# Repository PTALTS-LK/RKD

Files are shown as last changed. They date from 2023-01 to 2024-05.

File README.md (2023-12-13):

# RP2040-based Keyboard Devkit

**这是一个基于RP2040以及CH9329键鼠芯片的，使用Kicad6.0设计的一个开源音游控制器**

你也能当成一个可编程键盘使用

**使用MicroPython作为程序主控**
<!-- 只是一个高一学生用业余时间整出来的垃圾项目罢了，PCB布线设计以及代码什么的肯定有很多问题（ -->

<details><summary>

### 预览

</summary>

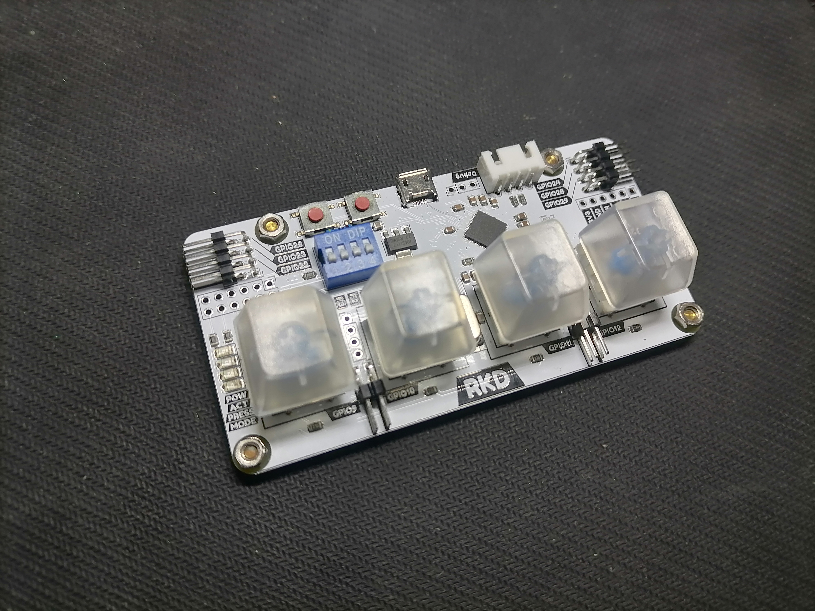
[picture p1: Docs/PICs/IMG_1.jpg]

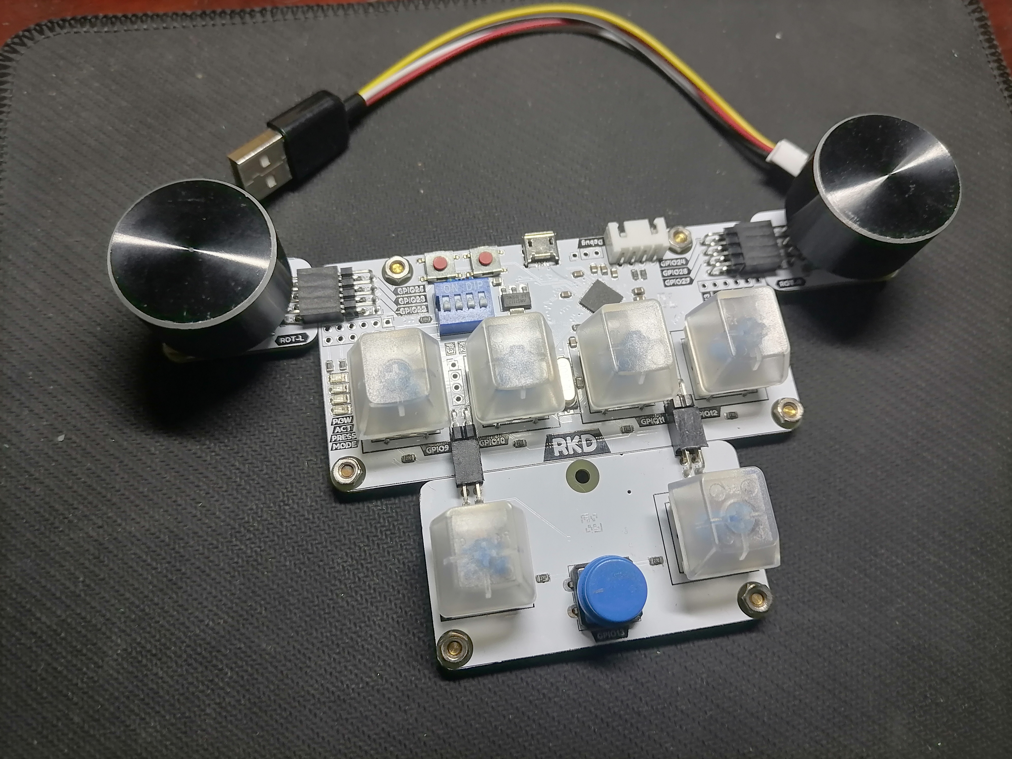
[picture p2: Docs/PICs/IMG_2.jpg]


</details>

## 特征：

  - （主要是）一个可编程键盘/4k音游控制器
    - PCB预设了SDVX的拓展板，也有只有主板的PCB
  - 使用CH9329键鼠芯片，可以模拟鼠标~~我没做~~或者键盘
  - 将RP2040的所有空闲GPIO和板载四个键使用排针引出
    - 可以用杜邦线外接按键/其他外设
    - 保留了SWD，你甚至当成一般的arm开发板进行开发
  - 键位可以~~不怎么~~方便的设置
    - 板上Flash fat32文件系统config.json，USB大容量设备写入有概率文件损坏，建议Thonny写入
    - 基于串口命令的设置系统,详见文档
  - 支持四种按键预设切换,通过板载DIP开关
  - 内置了宏执行器（格式请参照~~目前并不存在的~~文档）
  - 使用机械键盘键轴，可插拔（使用MX轴体）
  - 接口有MicroUSB和Type-C两种版本
  - ~~***没了***~~

## 项目文件结构
  [Docs](Docs) 各种文档

  [PCB](PCB) 当前版本的电路板Kicad设计文件

  [MPY_code](MPY_code) Micropython主控程序

  Micropython固件可在 [RKD-MpyPort](https://github.com/PTALTS-LK/RKD-MpyPort) 的Release页面找到

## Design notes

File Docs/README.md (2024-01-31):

# RKD文档

[Visual-BOM_gerber](Visual-BOM_gerber) 项目元件摆放位号的可视化BOM和gerber文件

[BOM.md](BOM.md) 项目的物料清单

[thonny_dev.md](thonny_dev.md) 更改键位和进行开发的说明（使用Thonny,不推荐用于修改键位）

[key_map.md](key_map.md) 按键对应键值的说明

[MAKE.md](MAKE.md) 制作注意事项

[Wire-key-positioning.md](Wire-key-positioning.md) 关于如何焊接钢丝键轴固定

[cdc_setting.md](cdc_setting.md) 通过串口来设置键位的说明

[RKD.dxf](RKD.dxf) 外壳切割文件

## 引脚图

RKD-Pinout

## 建议

**欢迎对文档提出建议或纠错**

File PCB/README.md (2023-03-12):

# PCB/原理图

- stand+sdvx :

  - 包含了主板和SDVX拓展板的PCB/原理图（单文件拼板）

- stand :

  - 只包含了主板PCB/原理图

子目录名称为对应接口版本的PCB/原理图

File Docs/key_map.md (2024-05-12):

# 按键键值对照

还可以参考MPY_code中[tools.py](https://github.com/PCX-LK/RKD-MpyCode/blob/979dd39ad3c4af1102518f772fbc5197f3a658ba/code/lib/tools.py)中的key_dict函数来设置键位

在串口中修改键位时,请不要带双引号

## 特殊键码

`NULL`  “空”按键，将按键设置为这个键码可以让按键空闲

## 数字键区

|按键名|对应键值|
| :---: | :---: |
|1 !|"1"|
|2 @|"2"|
|3 #|"3"|
|4 $|"4"|
|5 %|"5"|
|6 ^|"6"|
|7 &|"7"|
|8 *|"8"|
|9 (|"9"|
|0 )|"0"|

## 字母键区

|按键名|对应键值|
| :---: | :---: |
|Q|"Q"|
|W|"W"|
|E|"E"|
|R|"R"|
|T|"T"|
|Y|"Y"|
|U|"U"|
|I|"I"|
|O|"O"|
|P|"P"|
|A|"A"|
|S|"S"|
|D|"D"|
|F|"F"|
|G|"G"|
|H|"H"|
|J|"J"|
|K|"K"|
|L|"L"|
|Z|"Z"|
|X|"X"|
|C|"C"|
|V|"V"|
|B|"B"|
|N|"N"|
|M|'M'|

## 符号键区

|按键名|对应键值|
| :---: | :---: |
|\` ~|"`"|
|- _|"-"|
|= +|'='|
|\\ \||\\|
|; :|";"|
|' "|"'"|
|, <|"<"|
|. >|"."|
|/ ?|"/"|
|Space|" "|

## 功能键区

|按键名|对应键值|
| :---: | :---: |
|ESC|"ESC"|
|Enter|"Enter"|
|BackSpace|"BackSpace"|
|Tab|"Tab"|
|CapsLock|"CapsLock"|
|Left Shift|"ShiftL"|
|Right Shift|"ShiftR"|
|Left Ctrl|"CtrlL"|
|Right Ctrl|"CtrlR"|
|Left Alt|"AltL"
|Right Alt|"AltR"
|Left Win|"WinL"|
|Right Win|"WinR"|
|Insert|"Insert"|
|Delete|"Delete"|
|Home|"Home"|
|End|"End"|
|PrintScreen|"PrintScreen"|
|ScrollLock|"ScrollLock"|
|Pause|"Pause"|
|PageUp|"PageUp"|
|PageDown|"PageDown"|
|Application|"App"|
|UpArrow|"UpArrow"|
|DownArrow|"DownArrow"|
|LeftArrow|"LeftArrow"|
|RightArrow|"RightArrow"|

## Function键区

|按键名|对应键值|
| :---: | :---: |
|F1|"F1"|
|F2|"F2"|
|F3|"F3"|
|F4|"F4"|
|F5|"F5"|
|F6|"F6"|
|F7|"F7"|
|F8|"F8"|
|F9|"F9"|
|F10|"F10"|
|F11|"F11"|
|F12|"F12"|

# 小键盘区

|按键名|对应键值|
| :---: | :---: |
|NumLock|"NumLock"|
|/|"n/"|
|\*|"n\*"|
|-|"n-"|
|+|"n+"|
|.|"n."
|Enter|"nEnter"|
|1|"n1"|
|2|"n2"|
|3|"n3"|
|4|"n4"|
|5|"n5"|
|6|"n6"|
|7|"n7"|
|8|"n8"|
|9|"n9"|
|0|"n0"|

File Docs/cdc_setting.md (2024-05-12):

# 使用串口进行键位修改

最近的主控更新中更新了基于串口的指令设置方式（目前只支持更改按键）

支持PC（Windows,Linux,OSX）端以及Android端

## 安装串口通信软件

如果你有其他的串口软件并且会使用,可以不用完全按照下文来做

### PC端

请根据自己的平台前往COMTool的[Sourceforge](https://sourceforge.net/projects/comtool/files)下载安装文件

- Windows用户请下载`comtool_windows_<COMTool版本>.7z`
- Linux用户请下载`comtool_ubuntu_<COMTool版本>.tar.xz`结
- OSX用户请下载`comtool_macos_<COMTool版本>.dmg`

### Android端

请前往F-droid或者Google Play下载`Serial USB Terminal`

你还需要一根OTG线

## 使用串口通信软件连接RKD

连接之前确保RKD的`F3`没有上拨,如果上拨了,请拨下之后按下`RUN`按钮

### PC端 (COMTool)

使用调试线连接PC与RKD

连接之后打开`COMTool`

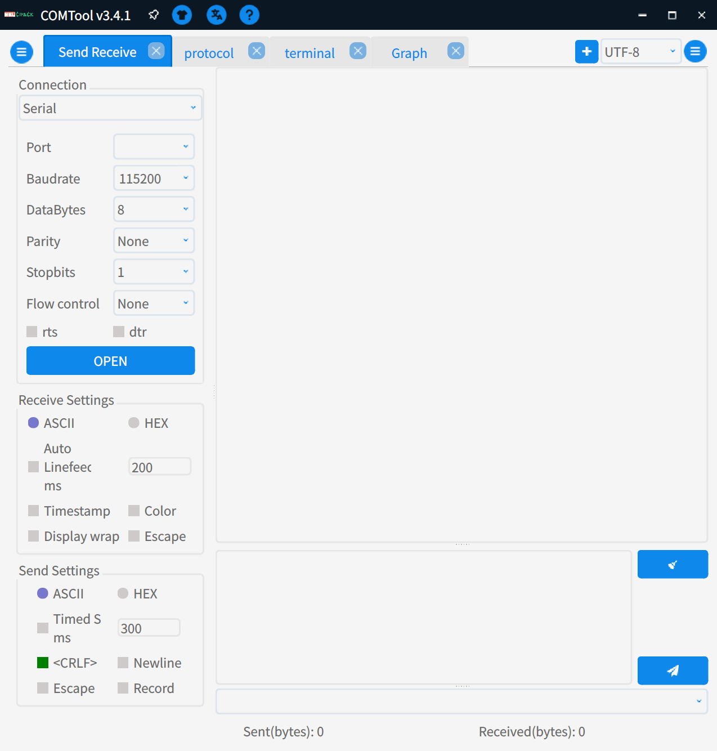
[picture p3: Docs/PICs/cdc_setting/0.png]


点击这个图标来设置语言，然后点击`Yes`来确认重启



`连接`面板配置:
- 打开`dtr`
- 点击`端口`下拉框来选择端口,应选择带有`RKD`字样的端口(Windows用户需要寻找`Microsoft - pid(0x04A0)`)
- 其余保持默认

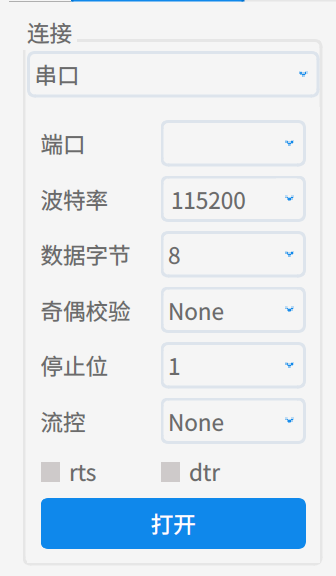
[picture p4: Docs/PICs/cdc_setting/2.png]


`发送设置`面板配置:
- 勾选`新行`
- 其余保持默认

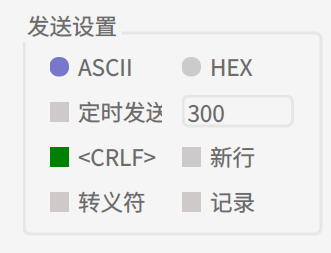
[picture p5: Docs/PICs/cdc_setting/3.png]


点击`连接`面板中的`打开`来连接到端口



之后上拨RKD的`F3`,此时接收面板应输出以下内容则证明连接成功

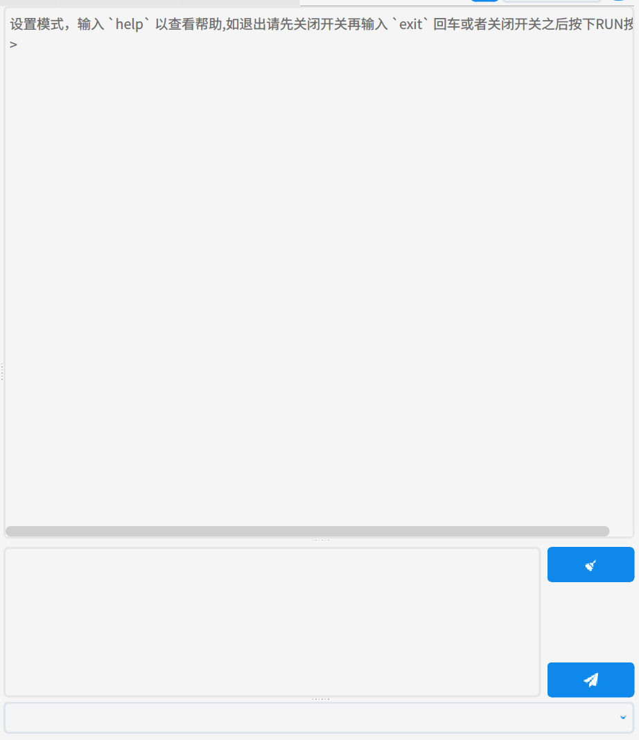
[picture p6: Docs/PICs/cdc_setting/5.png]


在发送面板输入`help`,然后按下右边的纸飞机(发送)按钮,接收面板内容应如下

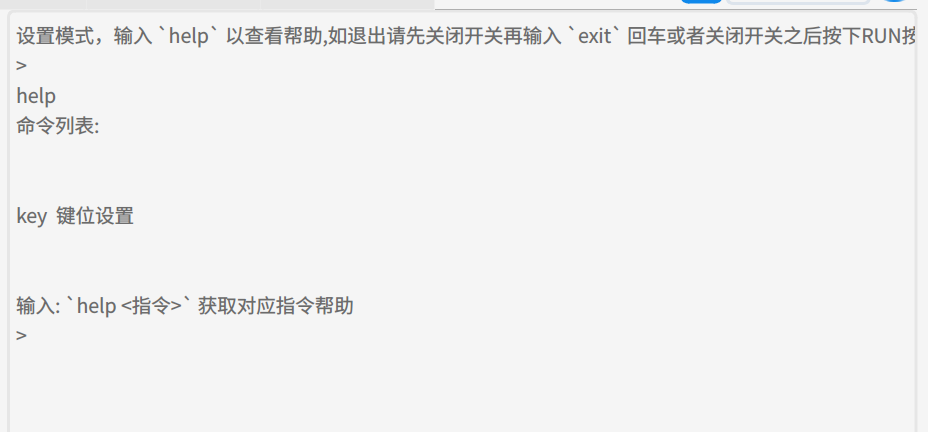
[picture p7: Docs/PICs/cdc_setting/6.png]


### 使用Thonny的shell来修改 (PC端)

先按照[thonnt_dev.md](thonny_dev.md)中的方法来配置thonny

然后使用调试线连接PC与RKD

打开`Thonny`,然后拨上RKD的`F3`,此时应该出现

th-o

进入设置模式成功

### Android端 (Serial USB Terminal)

使用OTG线+调试线连接RKD与Android设备

- 如果连接没有反应（RKD的电源指示灯`POW`未亮起）

  则有可能你的手机需要在设置中手动开启OTG功能，如何开启请根据自己的手机品牌型号自行百度

连接之后打开`Serial USB Terminal`

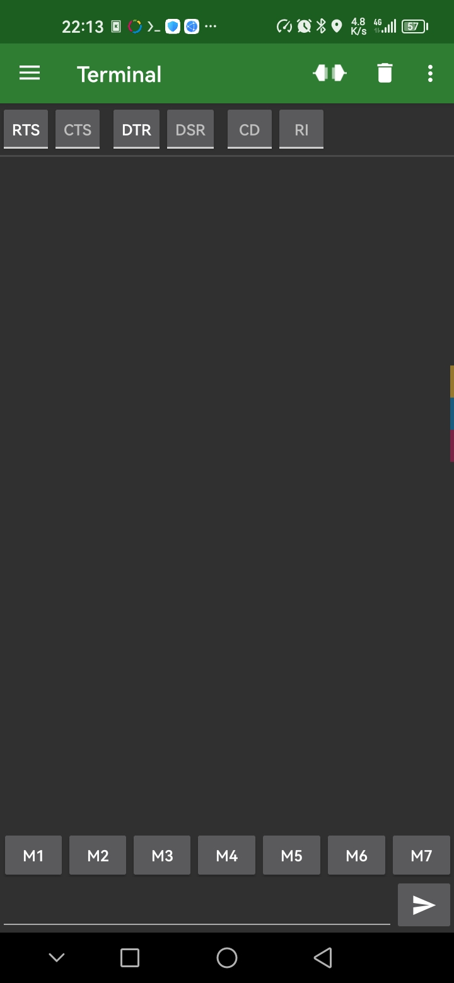
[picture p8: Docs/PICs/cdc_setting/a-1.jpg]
a-1


点击右上角的连接图标

a-2

此时应该会弹出一个授权窗口,点确定

然后上拨RKD的`F3`

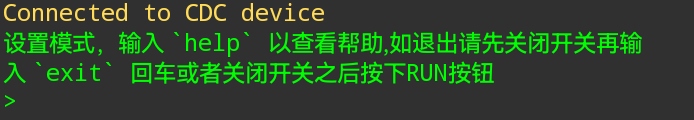
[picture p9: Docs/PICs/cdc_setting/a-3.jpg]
a-3


如果出现以上内容则证明连接成功

## 进行键位修改

可以先输入`help`来查看可用的命令

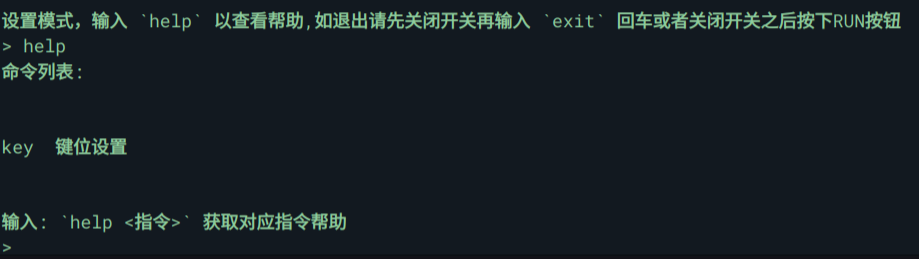
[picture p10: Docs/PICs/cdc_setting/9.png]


目前只有`key`,用于获取键位设置和修改键位

可以输入`help <指令>` (不需要添加尖括号) 来查看对应指令的参数帮助

### 命令

可以通过`key getKeyList`来获取所有按键所对应的键名,`key getKeyMap`来获取键值

然后通过`key setKeyValue`来设置键的映射:
- 语法：`key setKeyValue <键名> <键值1> <键值2> ....`
  一次只能设置一个键名对应的键值,可以有多个键值(可以实现组合键,同时按下的最多有效数量只有6个)
  修改的时候,注意RKD上`F1` `F2`的状态,这个两个开关决定了修改哪个预设组,用二进制的方式来设置预设组,上拨为1,下拨为0

  比如:
  ```
  F2  F1
  上  下
  ```
  对应二进制`10`,十进制`2`
  也就是3号预设
  ```
  F2  F1
  下  下
  ```
  对应二进制`00`,十进制`0`
  也就是1号预设
  
  对命令`key getKeyGroupValue`以及`key getKeyValue`同样生效

  在非设置模式下也是通过这个方式来切换预设组

  当boot_mode为0时才有效,为1时不支持多预设切换(只有一号预设组),目前boot_mode写死在了主控代码中(普通用户不用理会,默认为0)

`key getKeyGroupValue`和`key getKeyValue`:
- 用于获取整个当前预设组或者当前预设组特定键名对应按键键值
  `getKeyValue`需要指定键名,而`getKeyGroupValue`不需要(因为直接获取当前整个组)

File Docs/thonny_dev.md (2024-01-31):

# 使用Thonny IDE进行键位设置/开发

## 已不再推荐使用该方法修改键位

## 1 - 安装Thonny

### 1.1 - Windows

如果你是Windows用户，请前往Thonny的[官网](https://thonny.org/)或者Github的[Release页面](https://github.com/thonny/thonny/releases)下载exe安装程序

#### 1.1.1 - 在官网或在Github Release下载安装程序

**在Thonny官网或者Github Release页面下载安装程序**

##### **Thonny[官网](https://thonny.org/)**

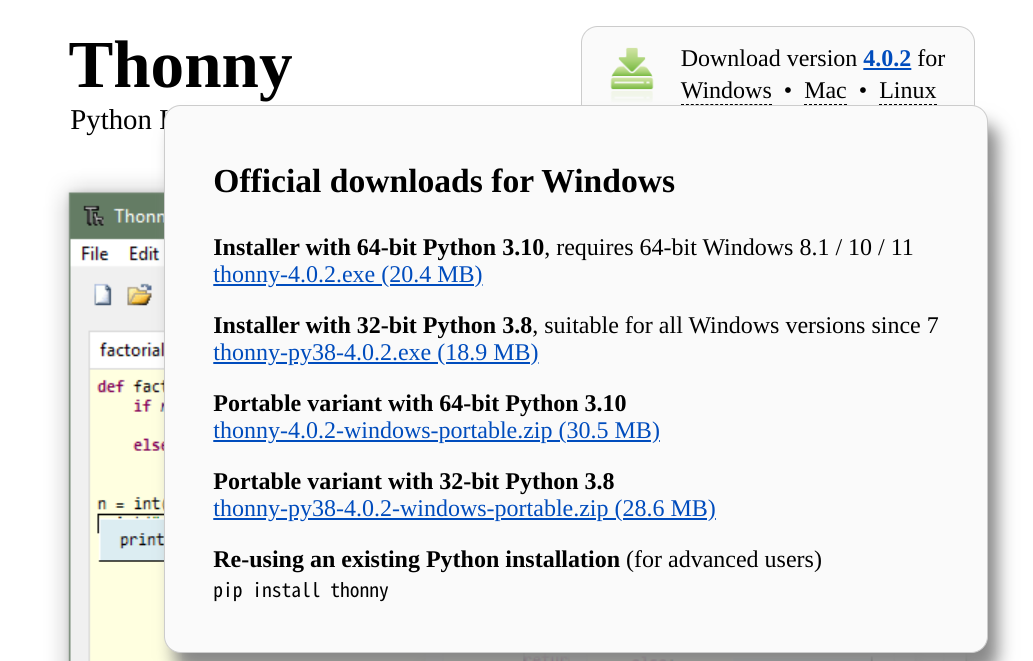
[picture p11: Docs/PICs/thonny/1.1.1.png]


鼠标悬浮在"Windows"上，会弹出菜单

如果你的系统是Win7或者是32位，则应该选择
```
Installer with 32-bit Python 3.8
thonny-py38-x.x.x.exe
```

如果是Win7以上而且是64位的系统，则应该选择
```
Installer with 64-bit Python 3.10
thonny-x.x.x.exe
```

##### **Github [Release页面](https://github.com/thonny/thonny/releases)**

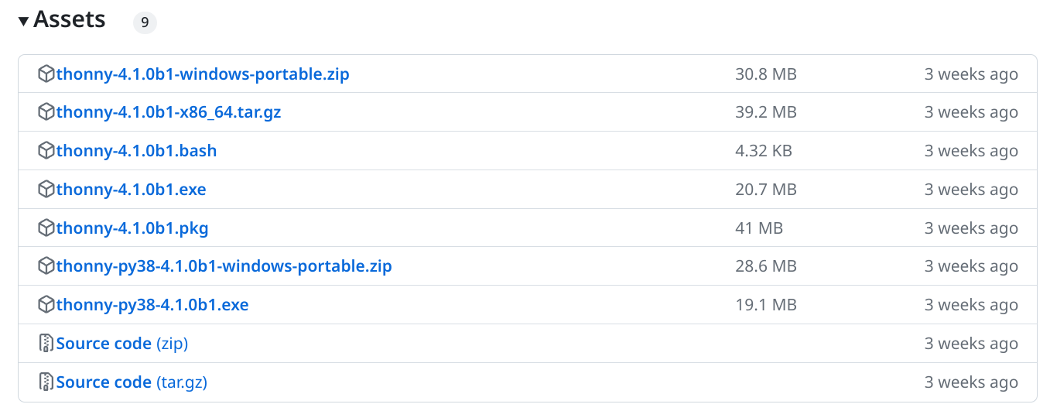
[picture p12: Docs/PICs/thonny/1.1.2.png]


在展开Assets之后

如果你的系统是Win7或者是32位，则应该选择
```
thonny-py38-x.x.x.exe
```

如果是Win7以上而且是64位的系统，则应该选择
```
thonny-x.x.x.exe
```

#### 1.1.3 - 运行安装程序

下载完毕后运行下载的exe进行安装，进入下一步

安装完后请从桌面的Thonny快捷方式或者开始菜单启动Thonny，而不是再次启动安装exe！

### 1.2 - Linux

如果你是Debian系用户，执行以下命令即可安装（其他发行版用户请自行摸索安装方法）

```
sudo apt install thonny -y
```

如果软件源的Thonny比较老，则再执行以下指令更新（推荐pip换源后执行）
```
pip install --upgrade thonny --break-system-packages
```

### 1.3 - OSX

高贵的Mac用户请自行摸索安装方法（（

## 2 - 设置Thonny

### 2.1 - 初始设置

首次启动thonny会弹出这个窗口

在这里选择语言和初始配置

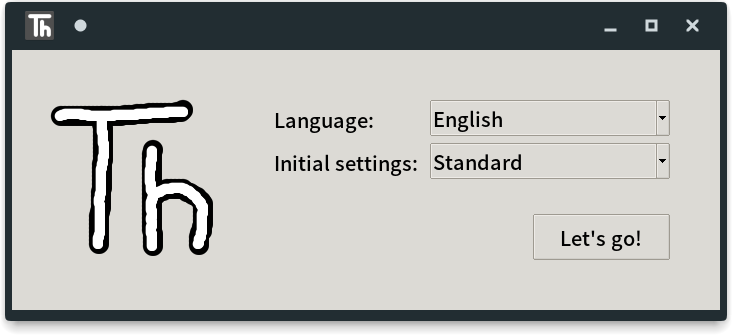
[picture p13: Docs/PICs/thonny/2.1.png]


"Language"不用说，直接选择"简体中文"

"Initial settings"是初始配置，这里原封不动选择"Standard"，不要选择"Raspberry pi"，界面布局会变成依托答辩

然后点击"Let's go!"进入下一步

### 2.2 - 界面布局设置

不出意外的话，你的界面应该是这个样子

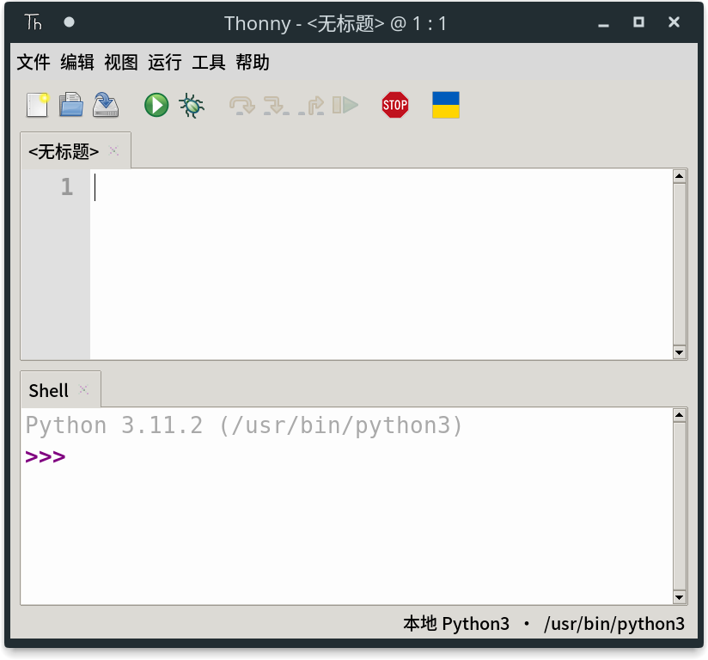
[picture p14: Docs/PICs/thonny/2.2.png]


点击工具栏中的"视图"，中勾选"文件"

这时视图应该会变成这样

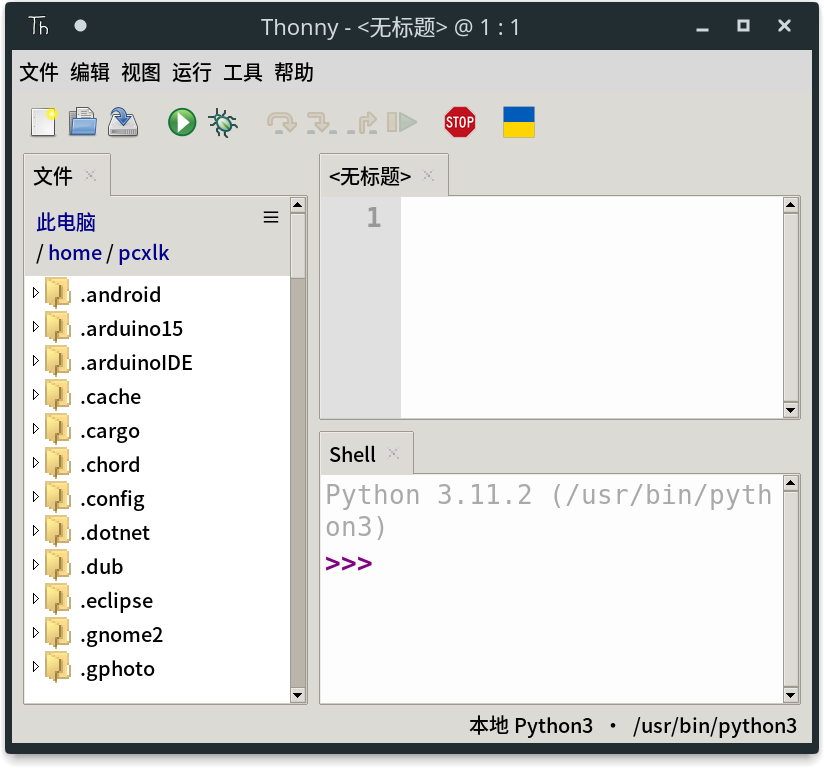
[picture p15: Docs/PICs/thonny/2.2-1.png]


### 2.3 - 设置解释器

现在thonny的默认解释器还是系统中/自带的Pyhon环境，我们需要将其切换到"Micropython"解释器

点击工具栏中的"运行"，在点击"选择解释器"，会弹出Thonny的设置窗口

将"Thonny 应该使用哪种解释器来运行您的代码？"下拉框的内容更改为"Micropython (通用)"或者"Micropython (RP2040)"

取消勾选"连接时中断运行中的程序"和"运行代码前，先重启解释器"复选框

设置完后界面应该是这样

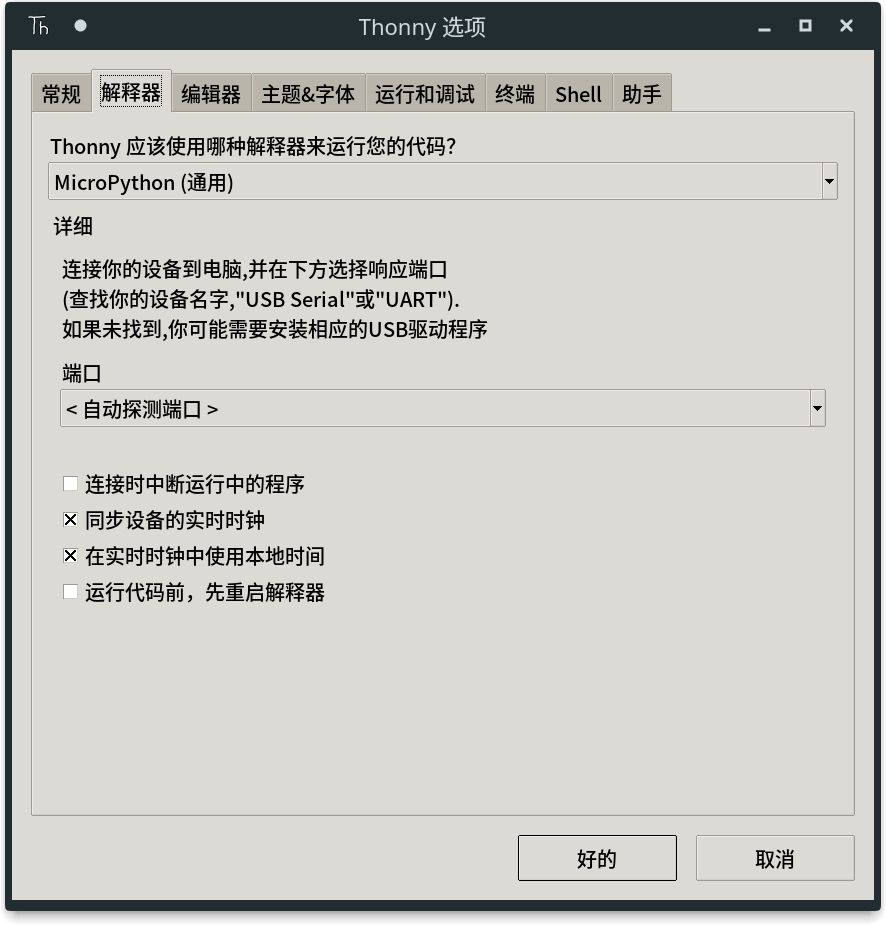
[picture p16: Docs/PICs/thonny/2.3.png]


点击"好的"保存退出设置

## 3 - 使用Thonny进行键位更改/开发
<!--  -->
### 3.1 - 连接RKD & 将Thonny连接到RKD上的MPY REPL

首先使用调试线连接RKD到电脑上，系统把设备设置完毕后会在资源管理器中多出一个3mib容量的usb存储设备，不要使用资源管理器打开它

回到Thonny，先按下界面左上方的红色"停止/重启后端进程"按钮或者按下Ctrl+F2

stop

如果界面底下shell面板输出如下（找无法自动找到设备）

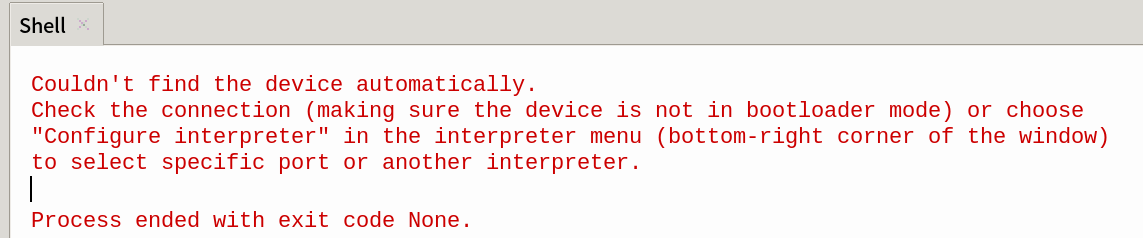
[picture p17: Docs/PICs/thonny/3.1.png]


请去设置解释器的页面中在端口下拉框中选择设备"Board in FS mode - Board CDC"



点击"好的"保存之后，shell面板应该输出如下，意思是设备忙于运行而无法响应

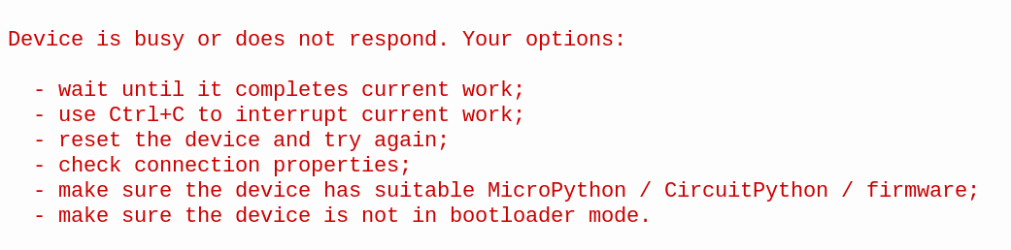
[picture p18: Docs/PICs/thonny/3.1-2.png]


所以要在shell面板里面按下Ctrl+C终止RKD板上主控的运行，此时应该输出为下

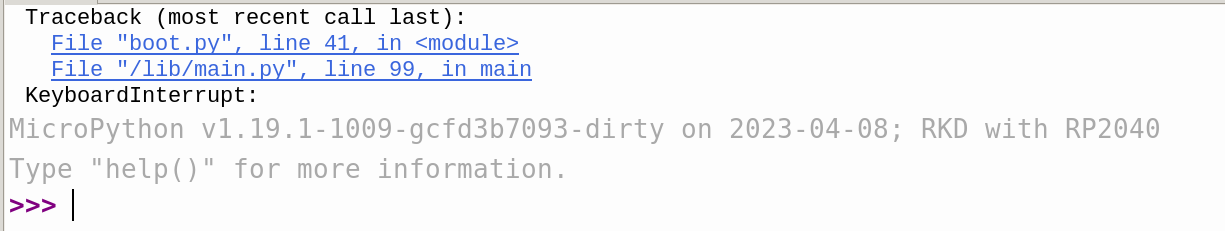
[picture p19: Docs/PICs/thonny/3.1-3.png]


然后你就会发现界面左边的"MicroPython设备"面板加载出了文件

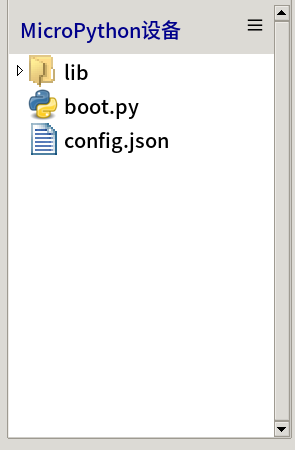
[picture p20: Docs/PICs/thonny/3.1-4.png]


这些文件储存在RKD主板上面的Flash中，"boot.py"文件和"lib"文件夹是RKD所运行的程序和依赖库

### 3.2 - 修改键位

只需要双击打开并修改"MicroPython设备"面板中的"config.json"就能修改键位

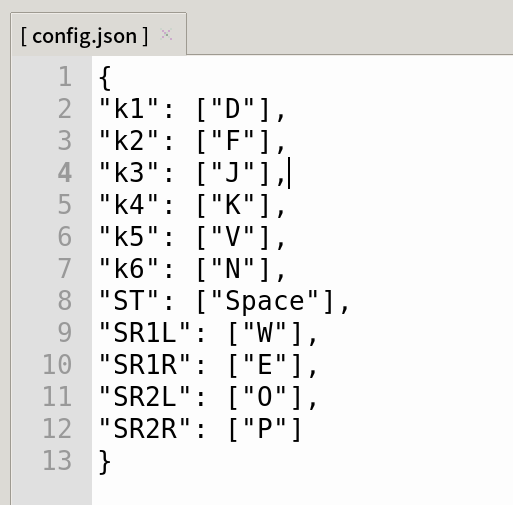
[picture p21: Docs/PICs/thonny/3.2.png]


冒号前面为按键，冒号后面为该键对应的键值

只需要修改键值就能更改键位

按键名对应：
```
主板部分：
k1 从左往右数第一个键
k2 从左往右数第二个键
k3 从左往右数第三个键
k4 从左往右数第四个键

SDVX扩展板部分：
k5 底板的从左往右第一个键
k6 底板的从左往右第二个键
ST 底板中间的按钮
SR1L 左旋钮逆时针旋转
SR1R 左旋钮顺时针选择
SR2L 右旋钮逆时针旋转
SR2R 右旋钮顺时针旋转
```

这些按键都可以设置组合键，只需要按照json的格式在按键后的数组中追加即可

键值对应请查看[key_map.md](key_map.md)

修改完成按Ctrl+S保存

然后在shell面板中按下Ctrl+D即可恢复运行，之后就可以关掉Thonny了

### 3.3 - 开发

可以参考网络上的使用Thonny IDE开发Micropython的教程

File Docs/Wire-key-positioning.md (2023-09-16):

# 钢丝键轴定位焊接说明

## 你需要什么

1. pcb中附带的钢丝辅助板
2. 0.5mm直径的304不锈钢钢丝
3. 能剪动2.中钢丝的尖嘴钳(可以单独使用强度够高的斜口钳,但是尖嘴钳还是需要的)
4. 电烙铁和焊锡
5. pcb(不可能没有吧)

## 步骤

### 1 - 使用钢丝辅助板弯折钢丝

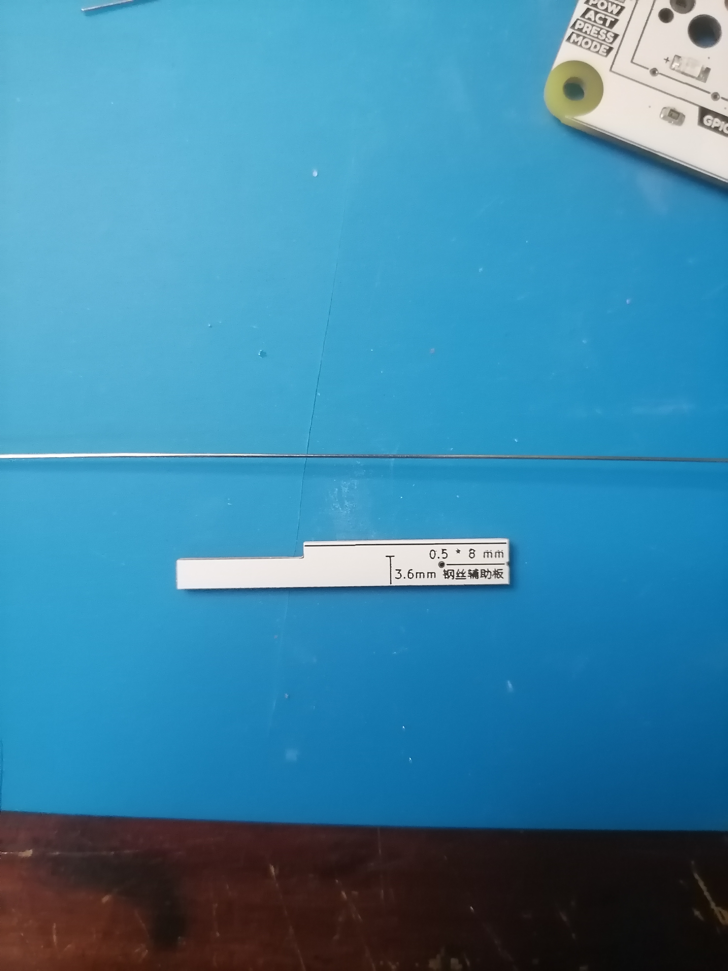
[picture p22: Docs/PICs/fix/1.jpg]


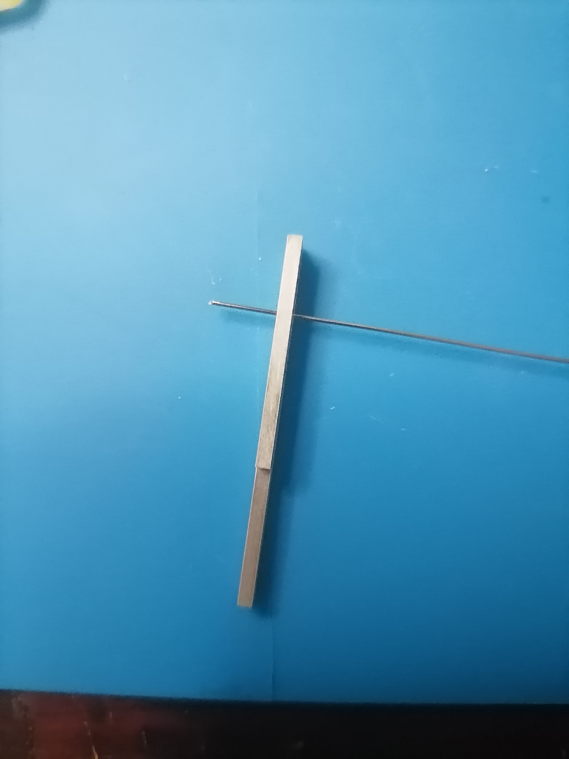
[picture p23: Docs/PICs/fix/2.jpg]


注意插入的长度,大约8mm左右就好

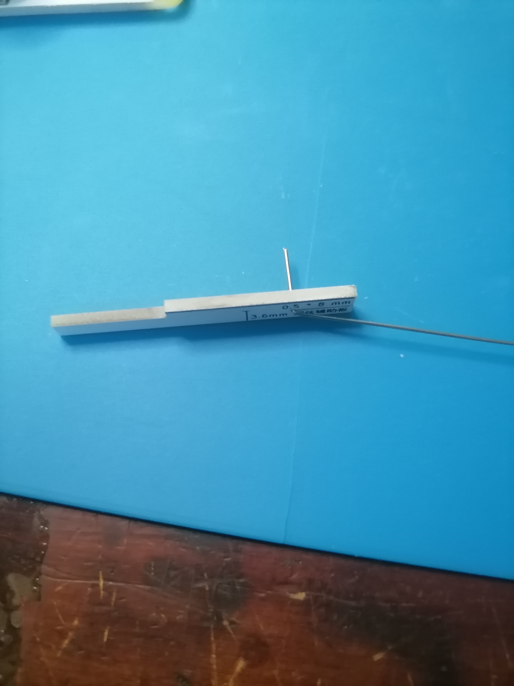
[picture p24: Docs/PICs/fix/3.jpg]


使用尖嘴钳弯折

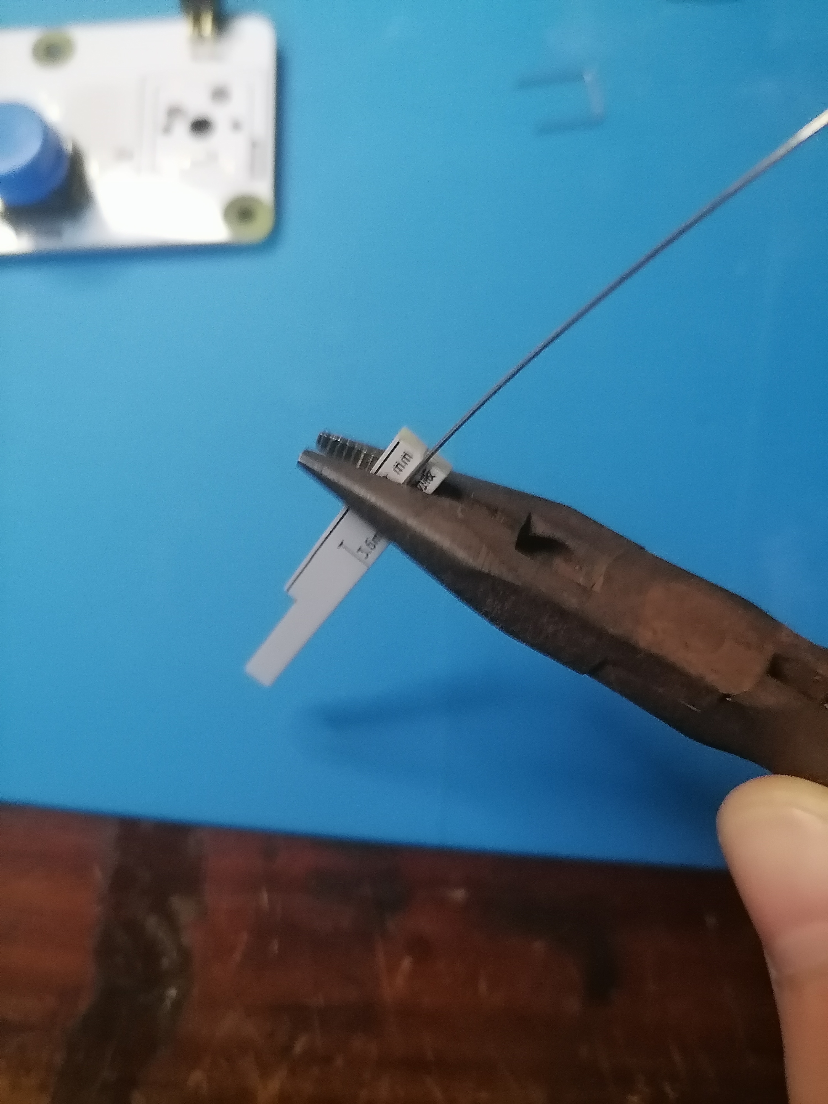
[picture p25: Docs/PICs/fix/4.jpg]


使用尖嘴钳把钢丝夹住,注意与线对齐

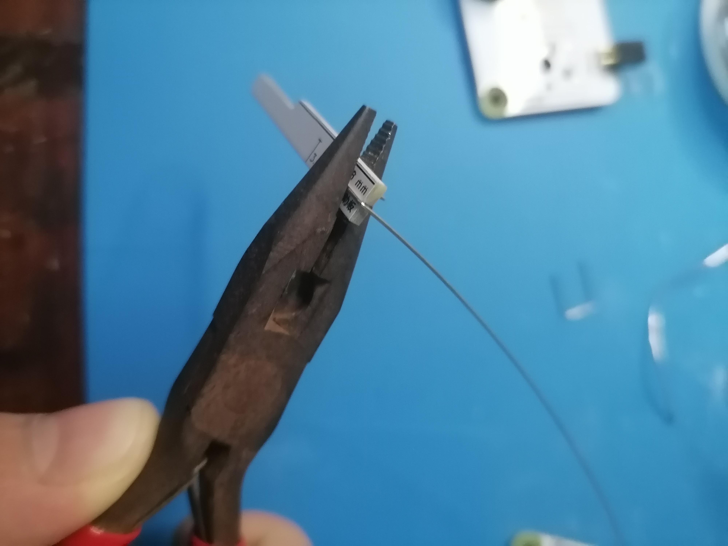
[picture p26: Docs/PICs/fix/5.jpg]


保持夹住,用手弯折钢丝,注意与辅助板边的半圆孔对齐



将其取出



将两边调整成直角



剪下,注意和另一边对齐

按照上述流程,为每个键制作2个

### 2 - 插入和继续弯折已弯折的钢丝



将弯折好的钢丝插入pcb的孔中



按照如图所示插入钢丝辅助板,靠近其中一边



用手按住钢丝使其紧贴钢丝辅助板,翻面,将靠近钢丝辅助板的一边的钢丝根据如图所示弯折



将钢丝辅助板取出,换一边插入



还是用手按住钢丝使其紧贴钢丝辅助板,翻面,将靠近钢丝辅助板的一边弯折



将钢丝辅助板取出,如图所示用手把钢丝按出



用尖嘴钳把弯折的部分继续向下弯折,小于90度就行,不要小于太多





把钢丝超出焊盘2/3的部分剪去(像图中这样小于1/2的也行,但是不建议)

然后按下去

按照上述流程重复处理所有的钢丝

### 3 - 焊接固定钢丝



插入钢丝辅助板,使其靠近其中一边(可能有点不好插入,可以尝试将其扳正之后插入)



然后翻面,使用电烙铁把焊锡填满焊盘把钢丝盖住



将钢丝辅助板换一边插入,同样用焊锡填满盖住

按照上述流程重复处理所有的钢丝

### 4 - 调整



如图所示,钢丝正面是歪的



直接用手扳正即可

按照上述流程重复处理所有的钢丝

**现在你应该可以直接插入键轴了**

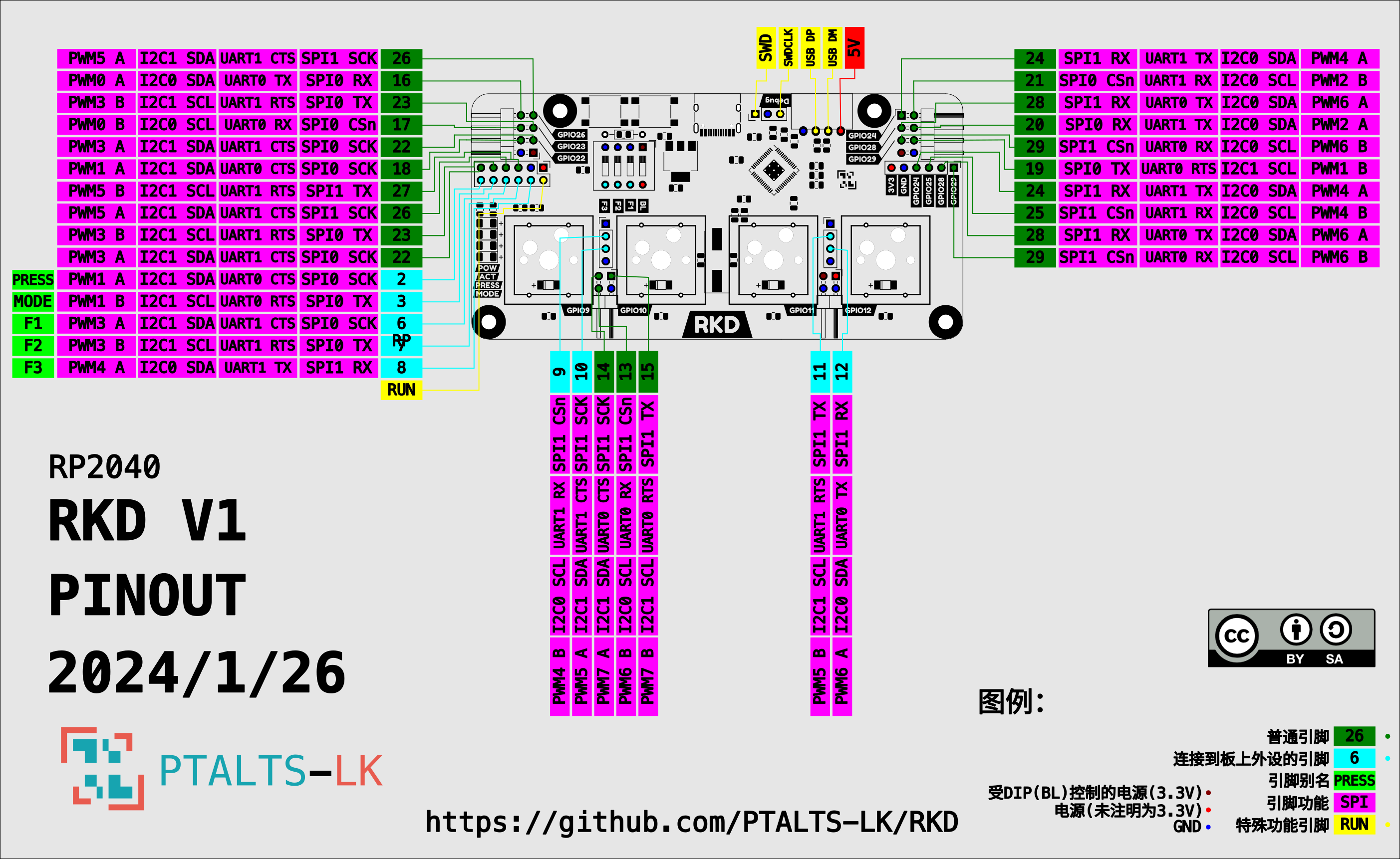
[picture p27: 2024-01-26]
Docs/PICs/RKD-Pinout.png

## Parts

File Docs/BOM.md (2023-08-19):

# 物料清单

关于元件位号和摆放可以查看 [Visual-BOM_gerber](Visual-BOM_gerber) 下的ibom.html可视化BOM文件

以下是该项目会用到的元件

部分元件存在以下情况：
  - 二选一（用‘/’分隔）
  - 其他特殊情况会单独列出

### 主板元件

|元件名（封装）|数量|元件位号|tb搜索关键词|
| :--- | :---: | :---: | :--- |
|100nf陶瓷电容（SMD 0805）|9|C7, C8, C9, C10, C11, C12, C13, C14, C15|贴片陶瓷电容 0805 100nf|
|1uf陶瓷电容（SMD 0805）|2|C1, C2|贴片陶瓷电容 0805 1uf|
|27pf陶瓷电容（SMD 0805）|2|C3, C4|贴片陶瓷电容 0805 27pf|
|10uf陶瓷电容（SMD 0805）|2|C5, C6|贴片陶瓷电容 0805 10uf|
|27ohm电阻（SMD 0805）|6|R1, R2, R5, R6, R7, R8|贴片电阻 0805 27欧姆|
|1k ohm电阻（SMD 0805）|6|R3, R13, R14, R15, R16, R17|贴片电阻 0805 1k欧姆|
|4.7k ohm电阻（直插/SMD 0805）|1|R18/R4|金属膜色环电阻 4.7k欧姆/贴片电阻 0805 4.7k欧姆|
|黄色LED（SMD 1206）|4|D1, D2, D3, D4|贴片LED 1206 黄色|
|蓝色LED（SMD 1206）|4|K1, K2, K3, K4|贴片LED 1206 蓝色|
|MX热插拔轴座（-）|4|K1, K2, K3, K4|键轴热插拔底座|
|w25q32jvsiq（SOP 8）|1|U1|w25q32|
|RP2040（QFN 56）|1|U2|RP2040 芯片|
|CH9329（SOP 16）|1|U3|CH9329|
|AMS1117（SOT 223）|1|U4|AMS1117 线性稳压器|
|12MHz晶振（HC49）|1|Y1/Y2|12MHz贴片晶振 HC49|
|6x6mm贴片开关（-）|2|SW3, SW5|贴片开关 6*6mm 4脚|
|DIP4开关（-）|1|SW2|拨码开关 4位|
|2x2 2.54mm弯排针（-）|2|J2, J4|双排针 弯针 2.54mm|
|2x4 2.54mm弯排针（-）|2|J3, J5|双排针 弯针 2.54mm|
|1x3 2.54mm直排针（-）|2|J13|单排针 直针 2.54mm|
|1x4 2.54mm直排针（-）|2|J14, J15|单排针 直针 2.54mm|
|1x6 2.54mm直排针（-）|1|J12|单排针 直针 2.54mm|
|2x6 2.54mm直排针（-）|1|J11|双排针 直针 2.54mm|
|XH2.54 4P弯针座（-）|1|J10|XH弯针座 2.54mm 4P|
|Type-C母座/MicroUSB母座（TYPE-C-31-M-12/5P4）|1|J1|TYPE-C-31-M-12/(MicroUSB 母座 5P4)|

### SDVX扩展子板元件

|元件名（封装）|数量|元件位号|tb搜索关键词|
| :--- | :---: | :---: | :--- |
|ec11旋转编码器（-）|2|SW6, SW8|ec11旋转编码器|
|蓝色LED（SMD 1206）|2|K5, K6|贴片LED 1206 蓝色|
|27ohm电阻（SMD 0805）|2|R10, R11|贴片电阻 0805 27欧姆|
|100nf陶瓷电容（SMD 0805）|4|C16, C17, C18, C19|贴片陶瓷电容 0805 100nf|
|12mm按键开关（-）|1|Sw7|按键开关 12*12mm|
|2x2 2.54mm弯排母（-）|2|J6, J9|双排母 弯针 2.54mm|
|2x4 2.54mm弯排母（-）|2|J7, J8|双排母 弯针 2.54mm|

### 仅Type-C版本需要元件

|元件名（封装）|数量|元件位号|tb搜索关键词|
| :--- | :---: | :---: | :--- |
|5.1k ohm电阻（SMD 0805）|2|R19, R20|贴片电阻 0805 5.1k欧姆|

### 其他特殊元件

|元件名（封装）|数量|元件位号|tb搜索关键词|说明|
| :--- | :---: | :---: | :--- | :---: |
|0ohm电阻（SMD 0805）|2|R9, R12|贴片电阻 0805 0欧|用于切换usb接口的连接，如果焊上0欧电阻则会把RP2040给连接到usb接口，此时CH9329会和RP2040冲突usb，故不能焊接CH9329|

### 调试线

XH2.54 4P 端子线
USB2公头

### 其他

如果使用凯华热插拔轴座,请注意焊接方向

你还需要0.5mm直径的304不锈钢丝用来固定键轴

key封装中的led以及指示led均可自行更换,但需要自行计算并更换限流电阻

需要安装主板外壳的话还需要m3\*3+4(顶面使用)以及m3\*3+3(底面使用)的铜柱各4个,m3螺母4个(固定顶面外壳),m3*4十字平头螺丝4个(固定底面外壳)

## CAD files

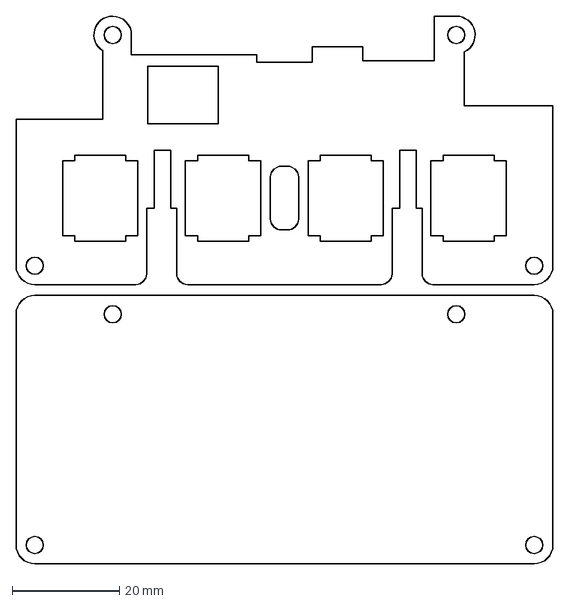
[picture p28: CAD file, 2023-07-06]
Docs/RKD.dxf
100.0 x 102.0 mm

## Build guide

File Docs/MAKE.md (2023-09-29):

# 制作说明

## 该项目使用了大量贴片元件,没有焊接经验的不建议复刻本项目

## 你会用到的工具

1. 电烙铁和焊锡
 - 这个不用多说吧,黄花907或者各种936焊台以及t12焊台都是不错的选择,电烙铁需要SK头(小刀头),焊锡推荐sn63/pb37的
2. 热风抢和锡膏
 - 焊贴片怎么能少得了这个工具,中温锡膏+280度热风刚好
3. 各种钳子
 - 尖嘴钳固定铜柱以及螺母必备,斜口钳剪剪钢丝必备
4. 陶瓷镊子
 - 用于夹持小元件,也是必要的
5. 加热台
 - 这个用于焊接单面大量贴片元件很好用,可选
6. 其他各种辅助(可选)
 - 隔热垫,夹具,吸锡器,吸锡带等等

## 重要提醒！

切割PCB时，请做好防护措施，切割产生的玻璃纤维会致癌，推荐使用kn95及以上等级的防尘面罩，同时做好通风

## 需要的材料

在[BOM.md](BOM.md)中有详细的物料清单,这里就不再赘述

## 焊接

交互式焊接位图在[Visual-BOM_gerber](Visual-BOM_gerber)中

除固定键轴用的钢丝外,无特殊焊接,按照常规进行焊接,钢丝焊接在[Wire-key-positioning.md](Wire-key-positioning.md)中有详细说明

## 关于外壳

目前只有主板有简单的透明亚克力壳
dxf文件在[RKD.dxf](RKD.dxf)

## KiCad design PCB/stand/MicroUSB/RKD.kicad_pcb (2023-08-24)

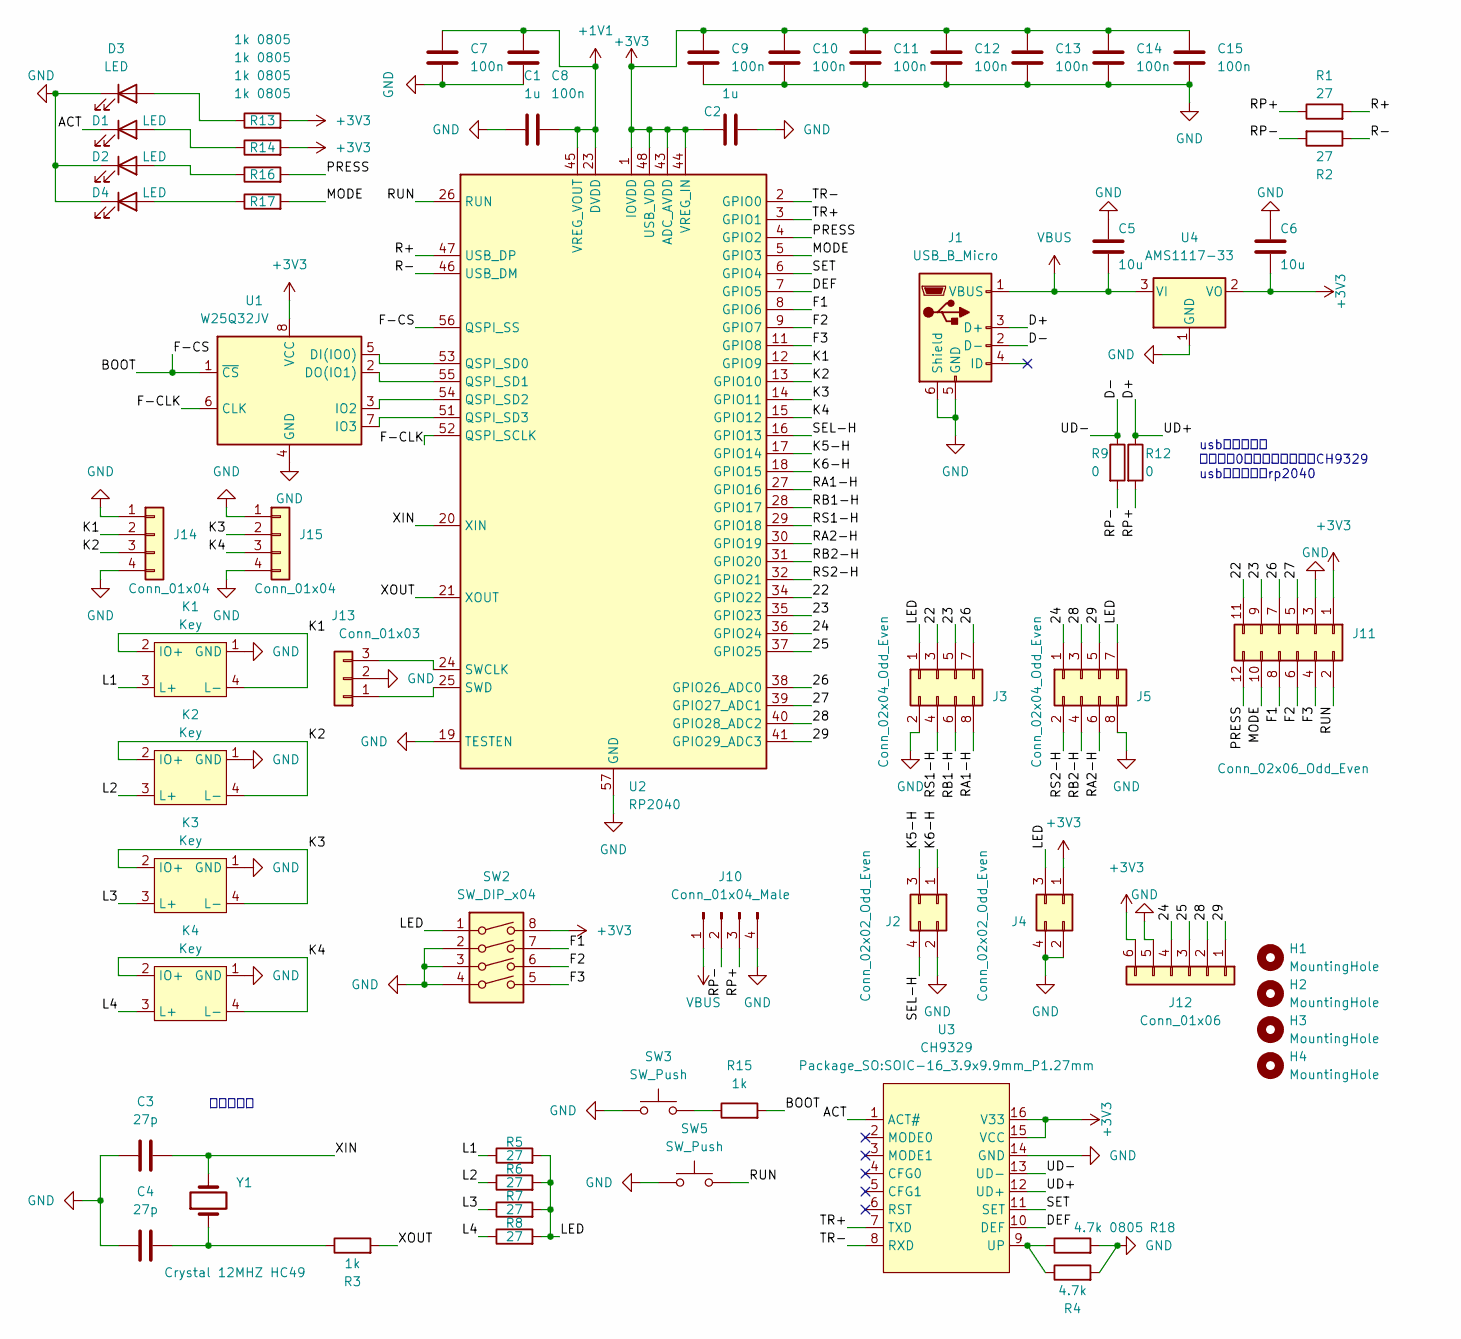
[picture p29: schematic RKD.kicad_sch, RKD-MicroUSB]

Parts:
C1, C2: 1u; C_0805_2012Metric
C3, C4: 27p; C_0805_2012Metric
C5, C6: 10u; C_0805_2012Metric
C7, C8, C9, C10, C11, C12, C13, C14, C15: 100n; C_0805_2012Metric
D1, D2, D3, D4: LED; L1206
H1, H2, H3, H4: MountingHole; HO
J1: USB_B_Micro; MICRO-USB-SMD_MICRO-4P-DIP-JB
J2, J4: Conn_02x02_Odd_Even; PinHeader_2x02_P2.54mm_Horizontal
J3, J5: Conn_02x04_Odd_Even; PinHeader_2x04_P2.54mm_Horizontal
J10: Conn_01x04_Male; XH-7mm
J11: Conn_02x06_Odd_Even; PinHeader_2x06_P2.54mm_Vertical
J12: Conn_01x06; PinHeader_1x06_P2.54mm_Vertical
J13: Conn_01x03; PinHeader_1x03_P2.54mm_Vertical
J14, J15: Conn_01x04; PinHeader_1x04_P2.54mm_Vertical
K1, K2, K3, K4: Key
R1, R2, R5, R6, R7, R8: 27; R_0805_2012Metric
R3, R15: 1k; R_0805_2012Metric
R4: 4.7k; R_Axial_DIN0204_L3.6mm_D1.6mm_P7.62mm_Horizontal
R9, R12: 0; R_0805_2012Metric
R13, R14, R16, R17: 1k 0805; R_0805_2012Metric
R18: 4.7k 0805; R_0805_2012Metric
SW2: SW_DIP_x04; SW_DIP_SPSTx04_Slide_9.78x12.34mm_W7.62mm_P2.54mm
SW3, SW5: SW_Push; SW_Push_1P1T_NO_6x6mm_H9.5mm
U1: W25Q32JV; SOIC-8_5.23x5.23mm_P1.27mm
U2: RP2040; RP2040-QFN-56
U3: CH9329; SOIC-16_3.9x9.9mm_P1.27mm
U4: AMS1117-33; SOT-223-3_TabPin2
Y1: Crystal 12MHZ HC49; Crystal_SMD_HC49-SD

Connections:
+1V1: C1.2, C7.2, C8.2, U2.23 (DVDD), U2.45 (VREG_VOUT), U2.50 (DVDD)
+3V3: C2.1, C6.1, C9.1, C10.1, C11.1, C12.1, C13.1, C14.1, C15.1, J4.1, J11.1, J12.6, R13.2, R14.2, SW2.8, U1.8 (VCC), U2.1 (IOVDD), U2.10 (IOVDD), U2.22 (IOVDD), U2.33 (IOVDD), U2.42 (IOVDD), U2.43 (ADC_AVDD), U2.44 (VREG_IN), U2.48 (USB_VDD), U2.49 (IOVDD), U3.15 (VCC), U3.16 (V33), U4.2 (VO)
/22: J3.3, J11.11, U2.34 (GPIO22)
/23: J3.5, J11.9, U2.35 (GPIO23)
/24: J5.1, J12.4, U2.36 (GPIO24)
/25: J12.3, U2.37 (GPIO25)
/26: J3.7, J11.7, U2.38 (GPIO26_ADC0)
/27: J11.5, U2.39 (GPIO27_ADC1)
/28: J5.3, J12.2, U2.40 (GPIO28_ADC2)
/29: J5.5, J12.1, U2.41 (GPIO29_ADC3)
/ACT: D1.1 (K), U3.1 (ACT#)
/BOOT: R15.2, U1.1 (~CS), U2.56 (QSPI_SS)
/D+: J1.3 (D+), R12.1, U3.12 (UD+)
/D-: J1.2 (D-), R9.1, U3.13 (UD-)
/DEF: U2.7 (GPIO5), U3.10 (DEF)
/F1: J11.8, SW2.7, U2.8 (GPIO6)
/F2: J11.6, SW2.6, U2.9 (GPIO7)
/F3: J11.4, SW2.5, U2.11 (GPIO8)
/F-CLK: U1.6 (CLK), U2.52 (QSPI_SCLK)
/K1: J14.2, K1.2 (IO+), K1.4 (L-), U2.12 (GPIO9)
/K2: J14.3, K2.2 (IO+), K2.4 (L-), U2.13 (GPIO10)
/K3: J15.2, K3.2 (IO+), K3.4 (L-), U2.14 (GPIO11)
/K4: J15.3, K4.2 (IO+), K4.4 (L-), U2.15 (GPIO12)
/K5-H: J2.3, U2.17 (GPIO14)
/K6-H: J2.1, U2.18 (GPIO15)
/L1: K1.3 (L+), R5.1
/L2: K2.3 (L+), R6.1
/L3: K3.3 (L+), R7.1
/L4: K4.3 (L+), R8.1
/LED: J3.1, J4.3, J5.7, R5.2, R6.2, R7.2, R8.2, SW2.1
/MODE: J11.10, R17.2, U2.5 (GPIO3)
/PRESS: J11.12, R16.2, U2.4 (GPIO2)
/R+: R1.2, U2.47 (USB_DP)
/R-: R2.1, U2.46 (USB_DM)
/RA1-H: J3.8, U2.27 (GPIO16)
/RA2-H: J5.6, U2.30 (GPIO19)
/RB1-H: J3.6, U2.28 (GPIO17)
/RB2-H: J5.4, U2.31 (GPIO20)
/RP+: J10.3, R1.1, R12.2
/RP-: J10.2, R2.2, R9.2
/RS1-H: J3.4, U2.29 (GPIO18)
/RS2-H: J5.2, U2.32 (GPIO21)
/RUN: J11.2, SW5.2, U2.26 (RUN)
/SEL-H: J2.4, U2.16 (GPIO13)
/SET: U2.6 (GPIO4), U3.11 (SET)
/TR+: U2.3 (GPIO1), U3.7 (TXD)
/TR-: U2.2 (GPIO0), U3.8 (RXD)
/XIN: C3.2, U2.20 (XIN), Y1.2
/XOUT: R3.2, U2.21 (XOUT)
GND: C1.1, C2.2, C3.1, C4.1, C5.2, C6.2, C7.1, C8.1, C9.2, C10.2, C11.2, C12.2, C13.2, C14.2, C15.2, D2.1 (K), D3.1 (K), D4.1 (K), J1.5 (GND), J1.6 (Shield), J2.2, J3.2, J4.2, J4.4, J5.8, J10.4, J11.3, J12.5, J13.2, J14.1, J14.4, J15.1, J15.4, K1.1 (GND), K2.1 (GND), K3.1 (GND), K4.1 (GND), R4.2, R18.2, SW2.2, SW2.3, SW2.4, SW3.1, SW5.1, U1.4 (GND), U2.19 (TESTEN), U2.57 (GND), U3.14 (GND), U4.1 (GND)
unnamed: C4.2, R3.1, Y1.1
unnamed: D1.2 (A), R14.1
unnamed: D2.2 (A), R16.1
unnamed: D3.2 (A), R13.1
unnamed: D4.2 (A), R17.1
unnamed: J13.1, U2.25 (SWD)
unnamed: J13.3, U2.24 (SWCLK)
unnamed: R15.1, SW3.2
unnamed: R4.1, R18.1, U3.9 (UP)
unnamed: U1.2 (DO(IO1)), U2.55 (QSPI_SD1)
unnamed: U1.3 (IO2), U2.54 (QSPI_SD2)
unnamed: U1.5 (DI(IO0)), U2.53 (QSPI_SD0)
unnamed: U1.7 (IO3), U2.51 (QSPI_SD3)
VBUS: C5.1, J1.1 (VBUS), J10.1, U4.3 (VI)

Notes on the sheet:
usb口连接切换 如果焊上0欧电阻则不能焊接CH9329 usb口会连接到rp2040
晶振二选一

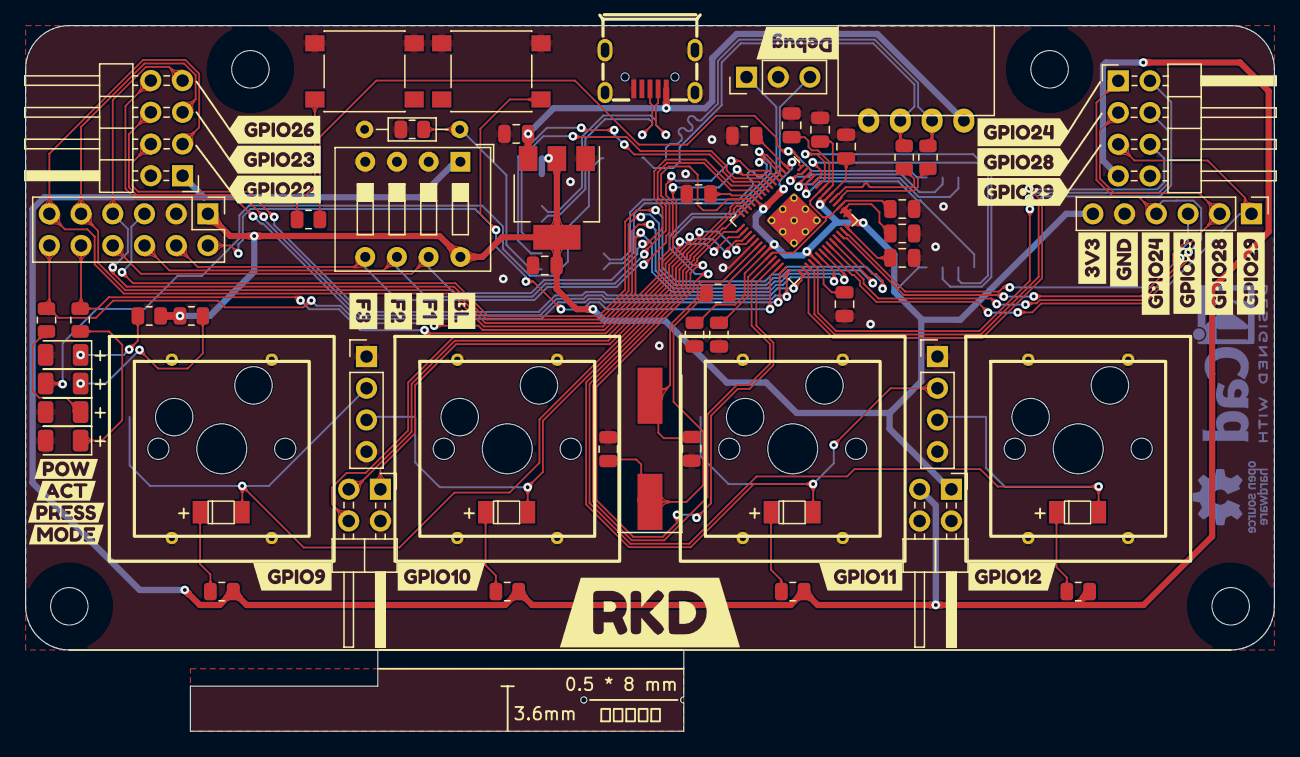
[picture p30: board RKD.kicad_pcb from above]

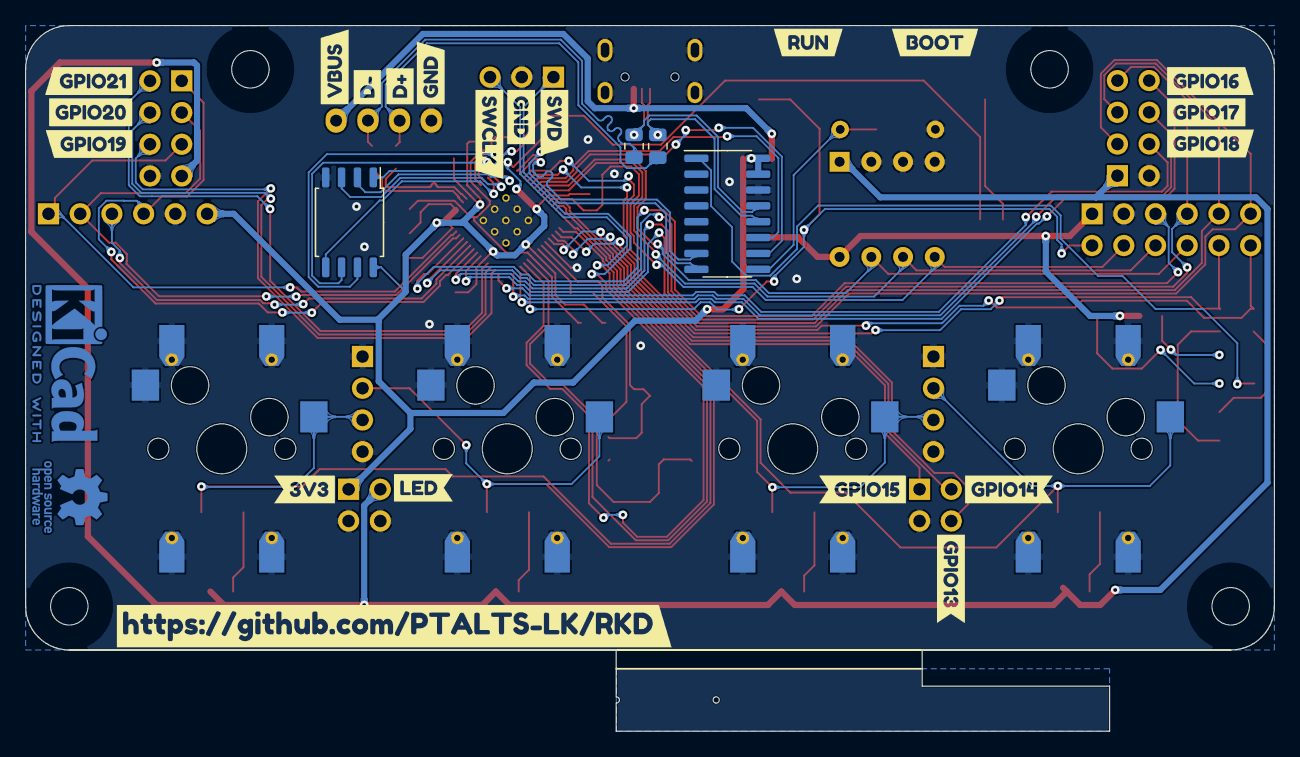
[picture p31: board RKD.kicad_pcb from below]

Board: 2 copper layers, 100.0 x 56.5 mm, 109 parts (25 on the bottom side), 64 nets.

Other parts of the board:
kibuzzard-63A1C2D7: G***; kibuzzard-63A1C2D7
kibuzzard-64E6F2B1: G***; kibuzzard-64E6F2B1
kibuzzard-635D2D2A: G***; kibuzzard-635D2D2A
kibuzzard-635D2D3A: G***; kibuzzard-635D2D3A
kibuzzard-635D2D4F: G***; kibuzzard-635D2D4F
kibuzzard-635D2D9C: G***; kibuzzard-635D2D9C
kibuzzard-635D2DDA: G***; kibuzzard-635D2DDA
kibuzzard-635D2DF8: G***; kibuzzard-635D2DF8
kibuzzard-635D2E5E: G***; kibuzzard-635D2E5E
kibuzzard-635D2E8C: G***; kibuzzard-635D2E8C
kibuzzard-635E2F9D: G***; kibuzzard-635E2F9D
kibuzzard-6354ECAF: G***; kibuzzard-6354ECAF
kibuzzard-6354ECBE: G***; kibuzzard-6354ECBE
kibuzzard-6354ECDD: G***; kibuzzard-6354ECDD
kibuzzard-6354F0BA: G***; kibuzzard-6354F0BA
kibuzzard-6354F0CA: G***; kibuzzard-6354F0CA
kibuzzard-6354F005: G***; kibuzzard-6354F005
kibuzzard-6354F197: G***; kibuzzard-6354F197
kibuzzard-6358CBD1: G***; kibuzzard-6358CBD1
kibuzzard-6358CBDF: G***; kibuzzard-6358CBDF
kibuzzard-6358CBEF: G***; kibuzzard-6358CBEF
kibuzzard-6358CC01: G***; kibuzzard-6358CC01
kibuzzard-6358CC12: G***; kibuzzard-6358CC12
kibuzzard-6379A323: G***; kibuzzard-6379A323
kibuzzard-6379ABBC: G***; kibuzzard-6379ABBC
kibuzzard-6379ABEB: G***; kibuzzard-6379ABEB
kibuzzard-6379AC10: G***; kibuzzard-6379AC10
kibuzzard-6379AC21: G***; kibuzzard-6379AC21
kibuzzard-6379AD0A: G***; kibuzzard-6379AD0A
kibuzzard-6379AD2A: G***; kibuzzard-6379AD2A
kibuzzard-6379AD8B: G***; kibuzzard-6379AD8B
kibuzzard-6379AD17: G***; kibuzzard-6379AD17
kibuzzard-6379AD65: G***; kibuzzard-6379AD65
kibuzzard-6379AD71: G***; kibuzzard-6379AD71
kibuzzard-6379AD90: G***; kibuzzard-6379AD90
kibuzzard-6379AEA3: G***; kibuzzard-6379AEA3
kibuzzard-6379AEAA: G***; kibuzzard-6379AEAA
kibuzzard-6379AEAF: G***; kibuzzard-6379AEAF
kibuzzard-6379AEB5: G***; kibuzzard-6379AEB5
kibuzzard-6379AEB9: G***; kibuzzard-6379AEB9
kibuzzard-6379AEBD: G***; kibuzzard-6379AEBD
kibuzzard-6379AEE6: G***; kibuzzard-6379AEE6
kibuzzard-6379B2A2: G***; kibuzzard-6379B2A2
kibuzzard-6379B2B1: G***; kibuzzard-6379B2B1
kibuzzard-6379B2D0: G***; kibuzzard-6379B2D0
kibuzzard-6379B2D8: G***; kibuzzard-6379B2D8
kibuzzard-6379B29B: G***; kibuzzard-6379B29B

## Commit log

2023-01-30 添加stand分离版本
    [RKD.kicad_pcb, RKD.kicad_sch, RKD_BOM.csv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]
2023-01-30 TypeC版本init
    [RKD-Bottom_Cu.gbr, RKD-Bottom_Mask.gbr, RKD-Bottom_Paste.gbr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]
2023-01-30 fix files
    [RKD-Bottom_Cu.gbr, RKD-Bottom_Mask.gbr, RKD-Bottom_Paste.gbr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]
2023-01-30 fix pcb
    [RKD.kicad_pcb]
2023-01-30 fix doc
    [RKD_BOM.csv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]
2023-02-04 修复typec版本的接口只能在特定一面使用
    [RKD.kicad_pcb, RKD.kicad_sch, RKD_BOM.csv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]
2023-03-12 upd pcb and md
    [RKD.kicad_pcb, RKD.kicad_sch]
2023-04-30 添加BOM.md以及同步mpy代码
2023-08-15 upd doc bom
2023-08-17 upd gerber
2023-08-17 upd bom.md
2023-08-19 紧急修复:经验证3225晶振无法稳定起振,故去除所以文件中的3225晶振
    [RKD.kicad_pcb, RKD.kicad_sch]
2023-09-17 主控升级
2023-11-26 更新,py代码重构,sdvx版pcb修改
    [RKD.kicad_sch]
2024-05-12 主控更新,文档更新
